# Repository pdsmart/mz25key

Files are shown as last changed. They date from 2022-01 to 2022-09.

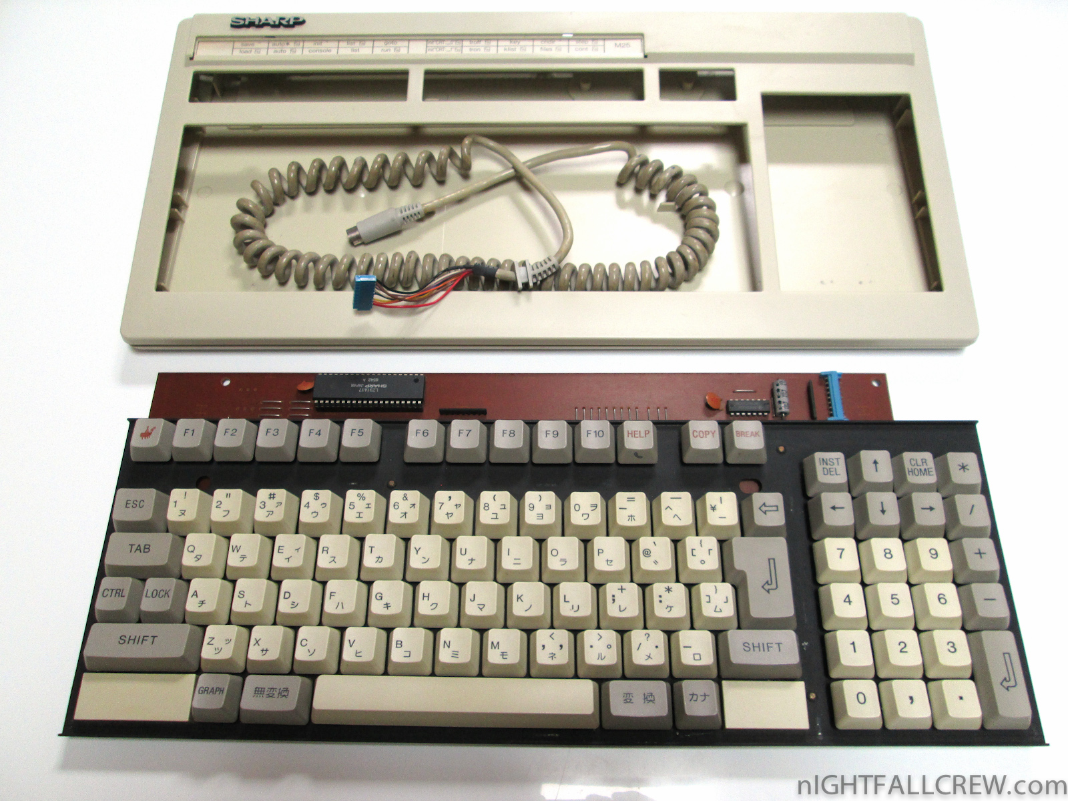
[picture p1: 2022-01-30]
docs/KeyboardImage.jpg

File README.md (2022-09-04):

# mz25key
A PS/2 to Sharp MZ-2500/MZ-2800 Interface

The mz25key now uses the SharKey firmware. If the build configuration (menuconfig -> SharpKey Configuration -> Build target -> mz25key
is set to an MZ2500 or MZ2800 then no changes are needed to hardware, just upload the firmware via the programmer port and once uploaded
future updates can be made via OTA. 

A modification can be made to an mz25key to allow it to run SharpKey firmware without specific build target. This can be achieved with a
100R resistor placed between pin14 (GPIO12) of the ESP32 and pin 8 of the host interface header J1. The advantage of this modification is it makes
the mz25key compatible with the SharpKey and if you used a 9pin header on the host interface, you can swap cables around to target different 
hosts.

Please see my website, https://eaw.app for more documentation and recent updates. 

The source code for the mz25key is identical to the SharpKey, just the build time configuration via the KConfig menu. The provided sdkconfig
is setup so that the source code will build the mz25key.

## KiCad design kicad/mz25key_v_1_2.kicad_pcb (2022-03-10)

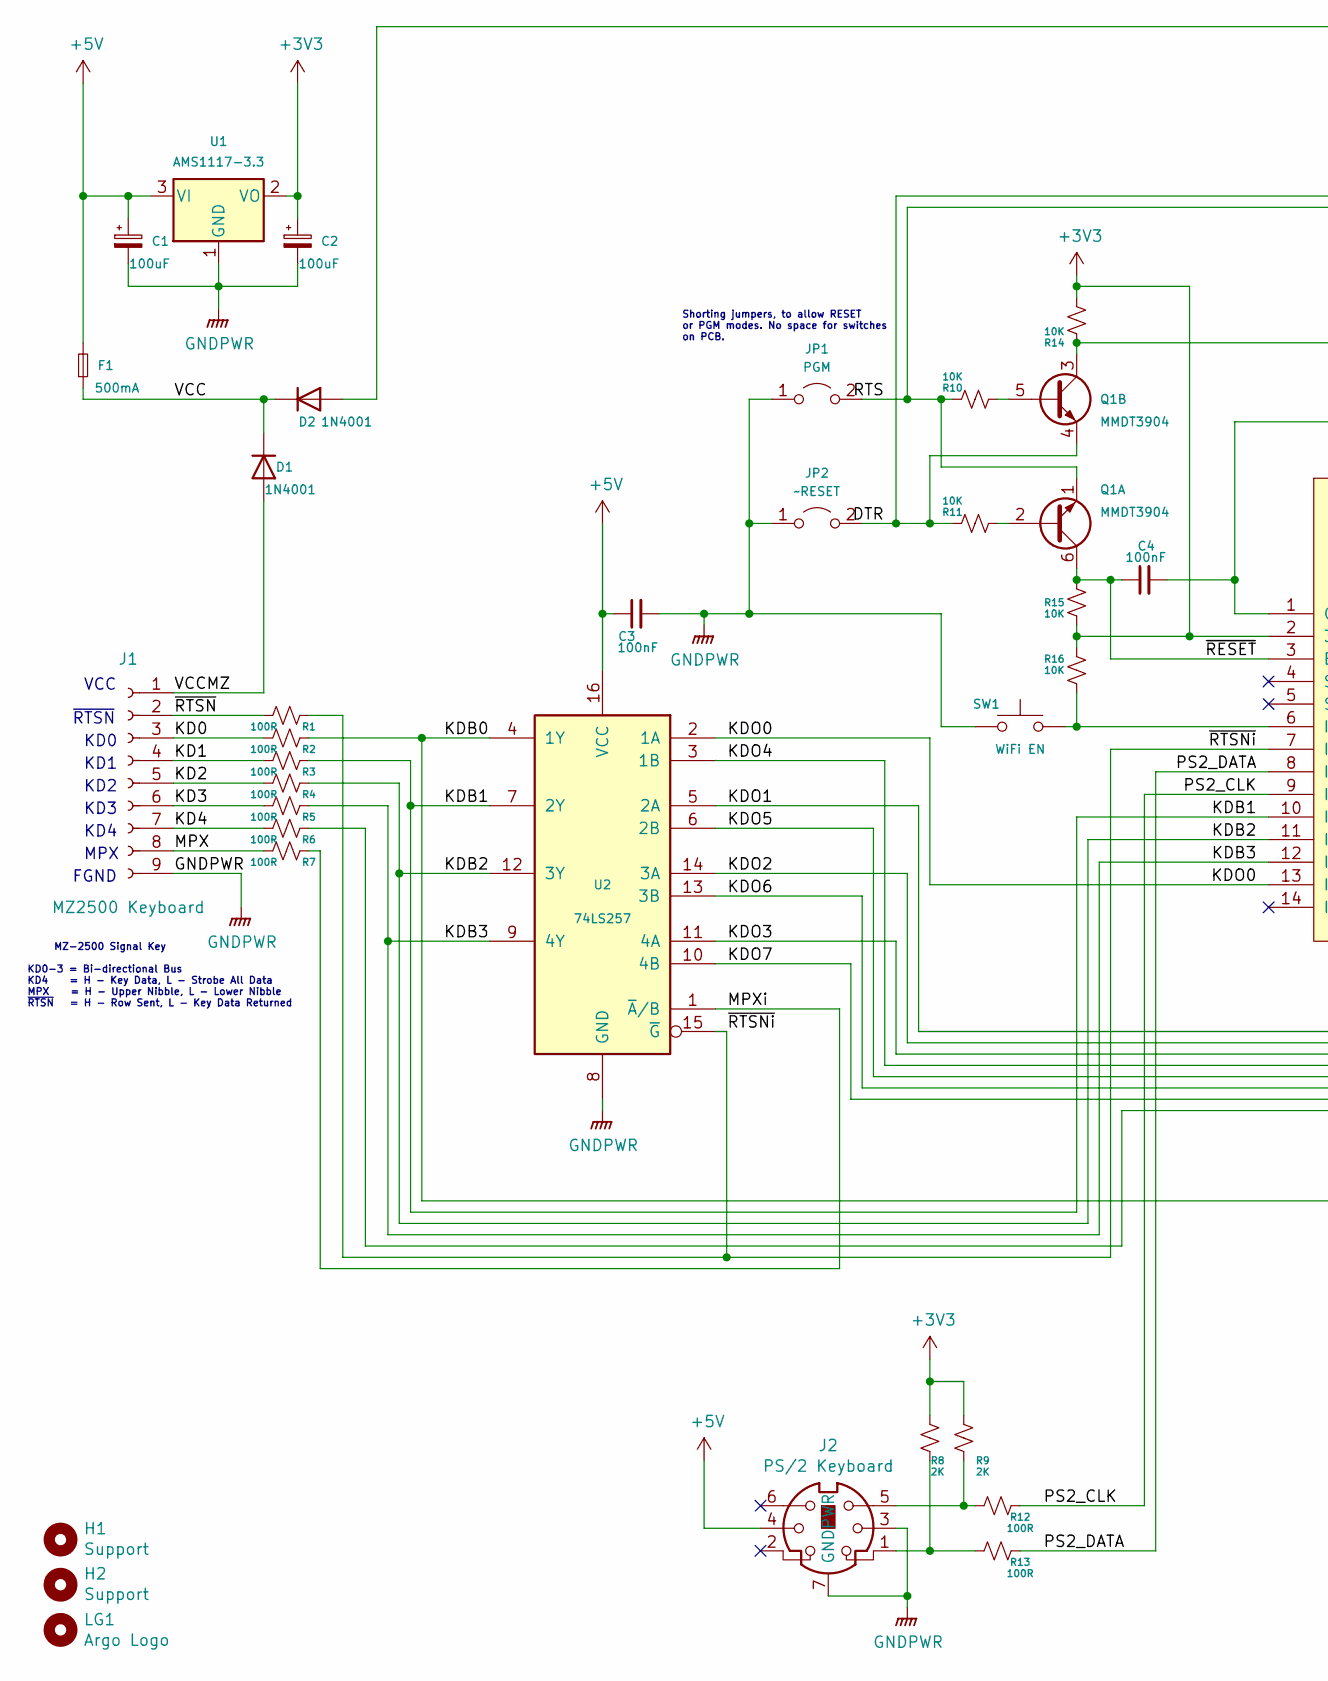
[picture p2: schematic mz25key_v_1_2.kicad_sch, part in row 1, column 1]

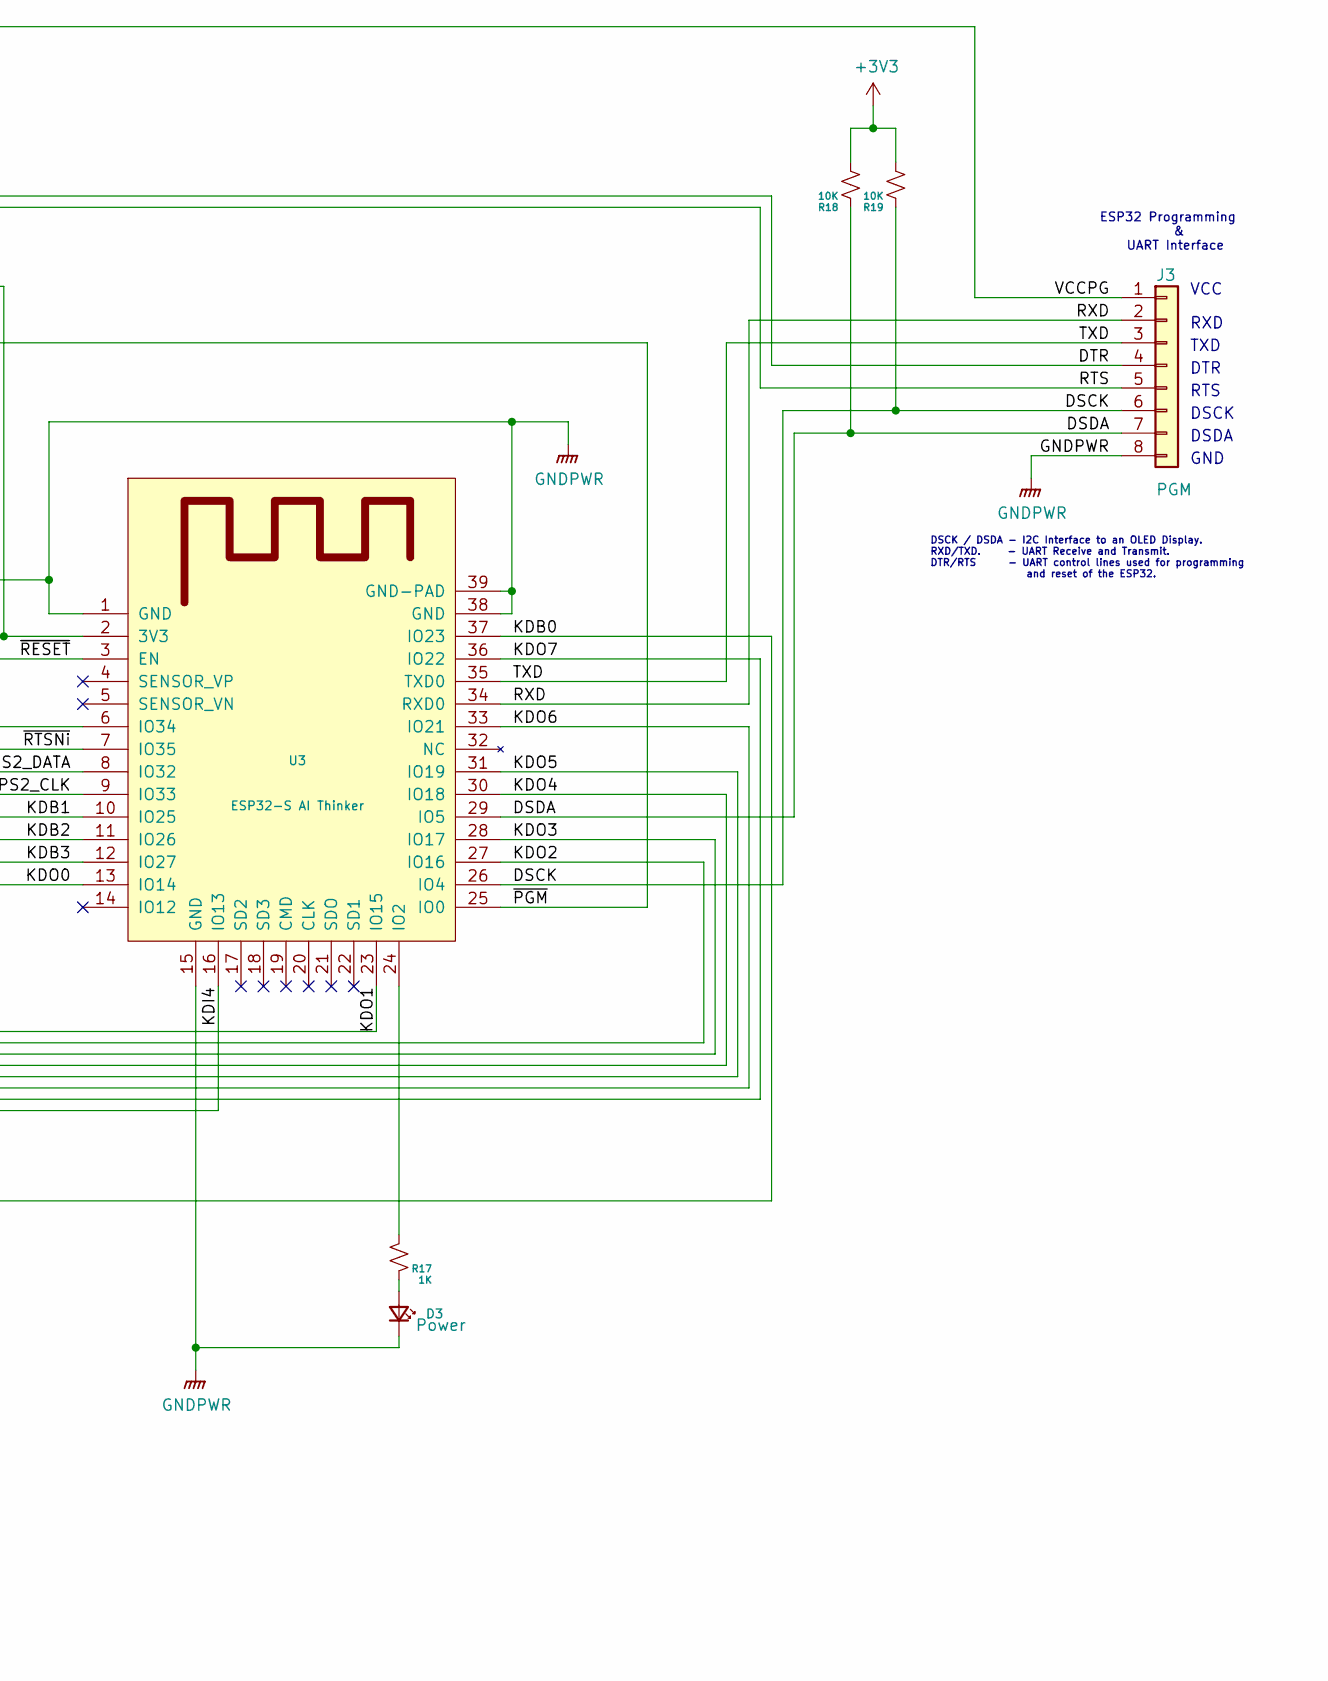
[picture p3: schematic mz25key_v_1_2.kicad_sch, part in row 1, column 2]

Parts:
C1, C2: 100uF; C_1210_3225Metric_Pad1.42x2.65mm_HandSolder
C3, C4: 100nF; C_0805_2012Metric
D1, D2: 1N4001; D_1206_3216Metric
D3: Power; LED_D3.0mm_Clear
F1: 500mA; Fuse_1806_4516Metric
H1, H2: Support; MountingHole_2.1mm
J1: MZ2500 Keyboard; PinHeader_1x09_P2.00mm_Vertical
J2: PS/2 Keyboard; Mini_din6_ps2
J3: PGM; PinHeader_1x08_P2.00mm_Vertical
JP1: PGM; PinHeader_1x02_P1.27mm_Vertical
JP2: ~RESET; PinHeader_1x02_P1.27mm_Vertical
LG1: Argo Logo; Argo
Q1: MMDT3904; SOT-363_SC-70-6
R1, R2, R3, R4, R5, R6, R7, R12, R13: 100R; R_0805_2012Metric
R8, R9: 2K; R_0805_2012Metric
R10, R11, R14, R15, R16, R18, R19: 10K; R_0805_2012Metric
R17: 1K; R_0805_2012Metric
SW1: WiFi EN; SW_SPST_B3S-1000
U1: AMS1117-3.3; SOT-223-3_TabPin2
U2: 74LS257; SOIC-16_3.9x9.9mm_P1.27mm
U3: ESP32-S AI Thinker; ESP32-S

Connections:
+3V3: C2.1, R8.1, R9.1, R14.2, R15.1, R16.2, R18.2, R19.2, U1.2 (VO), U3.2 (3V3)
+5V: C1.1, C3.1, F1.2, J2.4, U1.3 (VI), U2.16 (VCC)
/DSCK: J3.6, R19.1, U3.26 (IO4)
/DSDA: J3.7, R18.1, U3.29 (IO5)
/DTR: J3.4, JP2.2 (B), Q1.4 (E2), R11.2
/KD0: J1.3, R2.1
/KD1: J1.4, R3.1
/KD2: J1.5, R4.1
/KD3: J1.6, R5.1
/KD4: J1.7, R6.1
/KDB0: R2.2, U2.4 (1Y), U3.37 (IO23)
/KDB1: R3.2, U2.7 (2Y), U3.10 (IO25)
/KDB2: R4.2, U2.12 (3Y), U3.11 (IO26)
/KDB3: R5.2, U2.9 (4Y), U3.12 (IO27)
/KDI4: R6.2, U3.16 (IO13)
/KDO0: U2.2 (1A), U3.13 (IO14)
/KDO1: U2.5 (2A), U3.23 (IO15)
/KDO2: U2.14 (3A), U3.27 (IO16)
/KDO3: U2.11 (4A), U3.28 (IO17)
/KDO4: U2.3 (1B), U3.30 (IO18)
/KDO5: U2.6 (2B), U3.31 (IO19)
/KDO6: U2.13 (3B), U3.33 (IO21)
/KDO7: U2.10 (4B), U3.36 (IO22)
/MPX: J1.8, R7.1
/MPXi: R7.2, U2.1 (~A/B)
/PS2_CLK: R12.2, U3.9 (IO33)
/PS2_DATA: R13.2, U3.8 (IO32)
/RTS: J3.5, JP1.2 (B), Q1.1 (E1), R10.2
/RXD: J3.2, U3.34 (RXD0)
/TXD: J3.3, U3.35 (TXD0)
/VCC: D1.1 (K), D2.1 (K), F1.1
/VCCMZ: D1.2 (A), J1.1
/VCCPG: D2.2 (A), J3.1
/~PGM: Q1.3 (C2), R14.1, U3.25 (IO0)
/~RESET: C4.1, Q1.6 (C1), R15.2, U3.3 (EN)
/~RTSNi: R1.2, U2.15 (~G), U3.7 (IO35)
/~RTSN: J1.2, R1.1
GNDPWR: C1.2, C2.2, C3.2, C4.2, D3.1 (K), J1.9, J2.3, J2.7 (GNDPWR), J2.GND, J3.8, JP1.1 (A), JP2.1 (A), SW1.1, U1.1 (GND), U2.8 (GND), U3.1 (GND), U3.15 (GND), U3.38 (GND), U3.39 (GND-PAD)
unnamed: D3.2 (A), R17.2
unnamed: J2.1, R8.2, R13.1
unnamed: J2.5, R9.2, R12.1
unnamed: Q1.2 (B1), R11.1
unnamed: Q1.5 (B2), R10.1
unnamed: R16.1, SW1.2, U3.6 (IO34)
unnamed: R17.1, U3.24 (IO2)

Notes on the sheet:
KD3
Shorting jumpers, to allow RESET or PGM modes. No space for switches on PCB.
~{RTSN}
MPX
DSCK
DTR
RTS
KD2
TXD
VCC
ESP32 Programming & UART Interface
RXD
DSCK / DSDA - I2C Interface to an OLED Display. RXD/TXD. - UART Receive and Transmit. DTR/RTS - UART control lines used for programming and reset of the ESP32.
KD0
KD4
FGND
KD1
MZ-2500 Signal Key KD0-3 = Bi-directional Bus KD4 = H - Key Data, L - Strobe All Data MPX = H - Upper Nibble, L - Lower Nibble ~{RTSN} = H - Row Sent, L - Key Data Returned
DSDA
GND

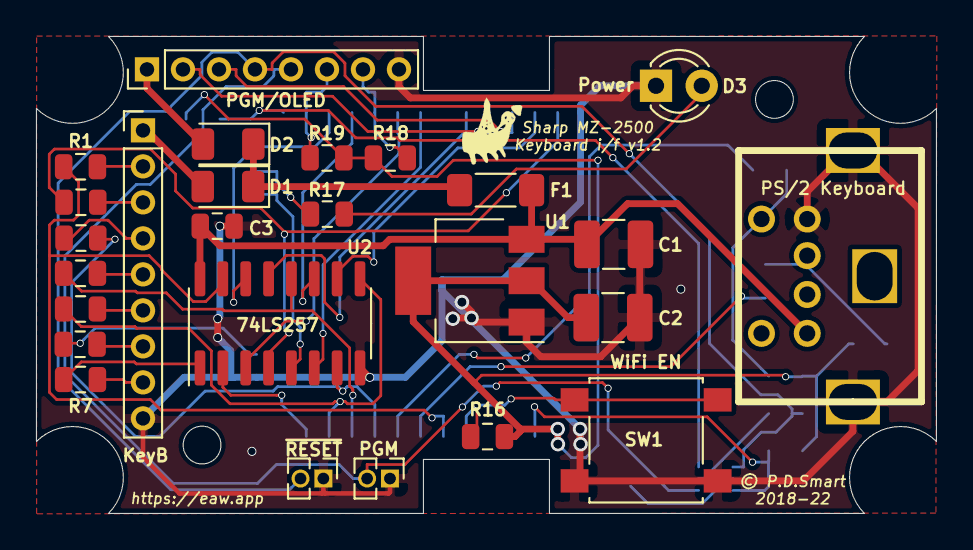
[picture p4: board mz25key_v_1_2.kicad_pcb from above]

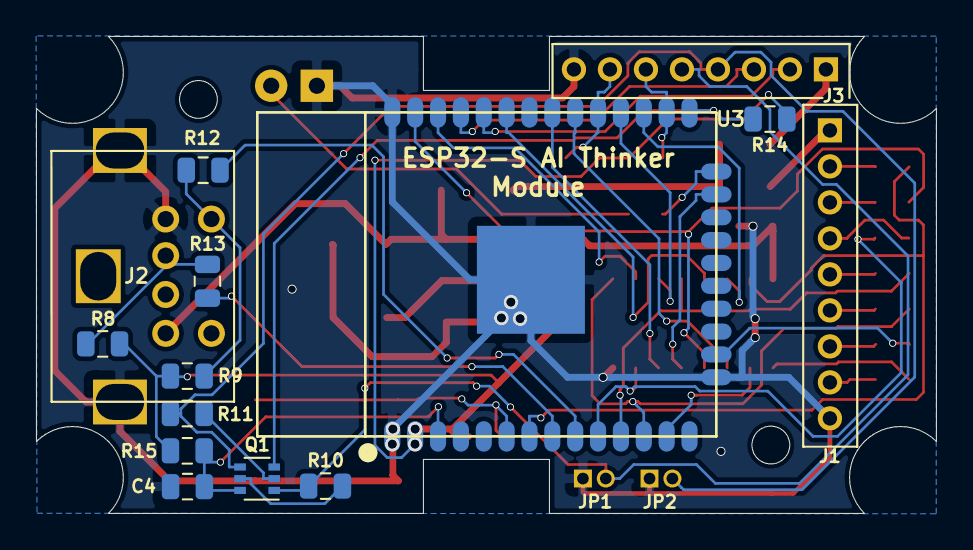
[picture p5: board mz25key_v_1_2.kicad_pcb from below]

Board: 2 copper layers, 50.0 x 26.5 mm, 40 parts (11 on the bottom side), 45 nets.

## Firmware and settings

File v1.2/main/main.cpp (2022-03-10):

/////////////////////////////////////////////////////////////////////////////////////////////////////////
//
// Name:            main.cpp
// Created:         Jan 2022
// Version:         v1.0
// Author(s):       Philip Smart
// Description:     MZ2500/2800 Key Matrix logic.
//                  This source file contains the application logic to obtain PS/2 scan codes, map them
//                  into a virtual keyboard matrix as per the Sharp MZ series key matrix and the
//                  logic to transmit the virtual key matrix to the MZ2500/2800.
//
//                  The application uses a modified version of the PS2KeyAdvanced 
//                  https://github.com/techpaul/PS2KeyAdvanced class from Paul Carpenter.
//
//                  The application uses, for debug purposes, the esp-idf-ssd1306 class from nopnop2002
//                  https://github.com/nopnop2002/esp-idf-ssd1306.
//
//                  The application uses the Espressif Development environment with Arduino components.
//                  This is necessary for the PS2KeyAdvanced class, which I may in future convert to
//                  use esp-idf library calls rather than Arduino.
//
//                  The Espressif environment is necessary in order to have more control over the build.
//                  It is important, for timing, that Core 1 is dedicated to MZ Interface 
//                  logic and Core 0 is used for all RTOS/Interrupts tasks. 
//
//                  The application is configured via the Kconfig system. Use 'idf.py menuconfig' to 
//                  configure.
// Credits:         
// Copyright:       (c) 2022 Philip Smart <philip.smart@net2net.org>
//
// History:         Jan 2022 - Initial write.
//                  Feb 2022 - Updates and fixes. Added logic to detect PS/2 disconnect and reconnect,
//                             added 3 alternative maps selected by ALT+F1 (MZ2500), ALT+F2(MZ2000)
//                             ALT+F3(MZ80B) due to slight differences in the key layout.
//                             Added framework for wifi so that the interface can enter AP mode to
//                             acquire local net parameters then connect to local net. Needs the web
//                             interface writing.
//
// Notes:           See Makefile to enable/disable conditional components
//
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
#include <stdio.h>
#include <stdlib.h>
#include <string.h>
#include "freertos/FreeRTOS.h"
#include "freertos/task.h"
#include "esp_log.h"
#if defined(CONFIG_MZ_WIFI_ENABLED)
  #include "freertos/event_groups.h"
  #include "esp_system.h"
  #include "esp_wifi.h"
  #include "esp_event.h"
  #include "nvs_flash.h"
  #include "lwip/err.h"
  #include "lwip/sys.h"
#endif
#include "Arduino.h"
#include "driver/gpio.h"
#include "soc/timer_group_struct.h"
#include "soc/timer_group_reg.h"
#include "PS2KeyAdvanced.h"
#include "MZKeyTable.h"
#include "ssd1306.h"
#include "font8x8_basic.h"
#include "sdkconfig.h"

//////////////////////////////////////////////////////////////////////////
// Important:
//
// All configuration is performed via the 'idf.py menuconfig' command.
// The file 'sdkconfig' contains the configured parameter defines.
//////////////////////////////////////////////////////////////////////////

// Macros.
//
#define NUMELEM(a)  (sizeof(a)/sizeof(a[0]))

// Structure to manage the translated key matrix. This is updated by the ps2Interface thread and read by the mzInterface thead.
typedef struct {
    uint8_t                     strobeAll;
    uint32_t                    strobeAllAsGPIO;
    uint8_t                     keyMatrix[16];
    uint32_t                    keyMatrixAsGPIO[16];
    uint8_t                     activeKeyMap;
} t_mzControl;
volatile t_mzControl            mzControl  = { 0xFF, 0x00000000, 
                                               { 0xFF, 0xFF, 0xFF, 0xFF, 0xFF, 0xFF, 0xFF, 0xFF, 0xFF, 0xFF, 0xFF, 0xFF, 0xFF, 0xFF, 0xFF, 0xFF}, 
                                               { 0x00000000, 0x00000000, 0x00000000, 0x00000000, 0x00000000, 0x00000000, 0x00000000, 0x00000000, 0x00000000, 0x00000000, 0x00000000, 0x00000000, 0x00000000, 0x00000000, 0x00000000  },
                                               MZ_ALL
                                             };

// Instantiate base classes. First, production required objects.
PS2KeyAdvanced                  Keyboard;

// Debug required objects.
SSD1306_t                       SSD1306;

// Handle to interact with the mz-2500/mz-2800 interface, ps/2 interface and wifi threads.
#if defined(CONFIG_MODEL_MZ2500)
    TaskHandle_t                TaskMZ25IF = NULL;
#endif
#if defined(CONFIG_MODEL_MZ2800)
    TaskHandle_t                TaskMZ28IF = NULL;
#endif
TaskHandle_t                    TaskPS2IF  = NULL;
#if defined(CONFIG_MZ_WIFI_ENABLED)
    TaskHandle_t                TaskWIFI   = NULL;
#endif

// Spin lock mutex to hold a core tied to an uninterruptable method. This only works on dual core ESP32's.
static portMUX_TYPE             mzMutex  = portMUX_INITIALIZER_UNLOCKED;

// Tag for ESP main application logging.
#if defined(CONFIG_MODEL_MZ2500)
  #define                       MAINTAG  "mz25key"
#endif
#if defined(CONFIG_MODEL_MZ2800)
  #define                       MAINTAG  "mz28key"
#endif

#if defined(CONFIG_MZ_WIFI_ENABLED)
    // The event group allows multiple bits for each event, but we only care about two events:
    // - we are connected to the AP with an IP
    // - we failed to connect after the maximum amount of retries 
    #define WIFI_CONNECTED_BIT  BIT0
    #define WIFI_FAIL_BIT       BIT1

    // Tag for ESP WiFi logging.
    #define                     WIFITAG  "wifi"

    // Menu selection types.
    enum WIFIMODES {
        WIFI_OFF              = 0x00,                             // WiFi is disabled.
        WIFI_ON               = 0x01,                             // WiFi is enabled.
        WIFI_CONFIG_AP        = 0x02                              // WiFi is set to enable Access Point to configure WiFi settings.
    };

    // Flag to indicate WiFi is active. Whilst active the MZ25 interface cannot run as it has to 
    // free the core. Need to find a way around this to make wifi only work on one core!
    static    bool              wifiActivated = 0;

    // FreeRTOS event group to signal when we are connected
    static EventGroupHandle_t   s_wifi_event_group;


    static int                  clientRetryCnt = 0;
#endif

#if defined(CONFIG_DEBUG_OLED) || !defined(CONFIG_OLED_DISABLED)
    // Printf to debug console terminal.
    void dbgprintf(const char * format, ...)
    {
        // Locals.
        va_list     ap;
    
        // Commence variable argument processing.
        va_start(ap, format);
        // Use vararg printf to expand and return the buffer size needed.
        int size = vsnprintf(nullptr, 0, format, ap) + 1;
        if (size > 0) 
        {
            va_end(ap);
    
            // Repeat and this time output the expanded string to a buffer for printing.
            va_start(ap, format);
            char buf[size + 1];
            vsnprintf(buf, size, format, ap);
    
            // Output to LED or console, currently via printf!
            printf(buf);
        }
        va_end(ap);
    }
#else
    #define dbgprintf(a, ...) {};
#endif

// Method to connect and interact with the MZ-2500 keyboard controller. This method is seperate from the MZ-2800
// as the scan is different and as it is time critical it is better to be per target machine.
//
// The basic requirement is to:
//   1. Detect a falling edge on the RTSN signal
//   2. Read the provided ROW number.
//   3. Lookup the matrix data for given ROW.
//   4. Output data to LS257 Mux.
//   5. Wait for RTSN to return inactive.
//   5. Loop
//
//   The ps2Interface method is responsible for obtaining a PS/2 Keyboard scancode and
//   creating the corresponding virtual matrix.
//
//   NB: As this method holds Core 1 under spinlock, no FreeRTOS or Arduino access 
//   can be made except for basic I/O ports. The spinlock has to be released for non
//   I/O work.
//
// The MZ timing period is ~600ns RTSN Low to High (Latch Row data coming from MZ machine),
// MPX (connected direct to external Quad 2-1 Mux goes high as RTSN goes low, the MPX
// signal is held high for 300ns then goes low for 300ns. The period when RTSN is low is
// when the MZ machine reads the scan row data. The cycle is ~1.2uS repeating, 14 rows
// so ~16.8uS for one full key matrix, The MZ machine if stuck in a tight loop will take
// approx 100uS to scan the matrix so the Gate Arrays are over sampling 6 times.
//
// WARNING: The GPIO's are configurable via menuconfig BUT it is assumed all except RTSNi
//          are in the first GPIO bank and RTSNi is in the second GPIO bank. Modify the code
//          if RTSNi is set in the first bank or KDB[3:0], KDI4 are in the second bank.
//
#if defined(CONFIG_MODEL_MZ2500)
    IRAM_ATTR void mz25Interface( void * pvParameters )
    {
        // Locals.
        volatile uint32_t gpioIN;
        volatile uint8_t  strobeRow = 1;
    
        // Mask values declared as variables, let the optimiser decide wether they are constants or placed in-memory.
        uint32_t          rowBitMask = (1 << CONFIG_MZ_KDB3) | (1 << CONFIG_MZ_KDB2) | (1 << CONFIG_MZ_KDB1) | (1 << CONFIG_MZ_KDB0);
        uint32_t          colBitMask = (1 << CONFIG_MZ_KDO7) | (1 << CONFIG_MZ_KDO6) | (1 << CONFIG_MZ_KDO5) | (1 << CONFIG_MZ_KDO4) | 
                                       (1 << CONFIG_MZ_KDO3) | (1 << CONFIG_MZ_KDO2) | (1 << CONFIG_MZ_KDO1) | (1 << CONFIG_MZ_KDO0);
        uint32_t          KDB3_MASK  = (1 << CONFIG_MZ_KDB3);
        uint32_t          KDB2_MASK  = (1 << CONFIG_MZ_KDB2);
        uint32_t          KDB1_MASK  = (1 << CONFIG_MZ_KDB1);
        uint32_t          KDB0_MASK  = (1 << CONFIG_MZ_KDB0);
        uint32_t          KDI4_MASK  = (1 << CONFIG_MZ_KDI4);
        uint32_t          RTSNI_MASK = (1 << (CONFIG_MZ_RTSNI - 32));
    
        ESP_LOGI(MAINTAG, "Starting mz25Interface thread, colBitMask=%08x, rowBitMask=%08x.", colBitMask, rowBitMask);
    
        // Create, initialise and hold a spinlock so the current core is bound to this one method.
        portENTER_CRITICAL(&mzMutex);
    
        // Permanent loop, just wait for an RTSN strobe, latch the row, lookup matrix and output.
        // Timings with Power LED = LED Off to On = 108ns, LED On to Off = 392ns
        for(;;)
        {
            #if defined(CONFIG_MZ_WIFI_ENABLED)
                // Whilst Wifi is active, suspend processing as we need to free up the core.
                if(wifiActivated)
                {
                    portEXIT_CRITICAL(&mzMutex);
                    while(wifiActivated);
                portENTER_CRITICAL(&mzMutex);
                }
            #endif
    
            // Detect RTSN going high, the MZ will send the required row during this cycle.
            if(REG_READ(GPIO_IN1_REG) & RTSNI_MASK)
            {
                // Read the GPIO ports to get latest Row and KDI4 states.
                gpioIN = REG_READ(GPIO_IN_REG);
    
                // Assemble the required matrix row from the configured bits.
                strobeRow = ((gpioIN&KDB3_MASK) >> (CONFIG_MZ_KDB3-3)) | ((gpioIN&KDB2_MASK) >> (CONFIG_MZ_KDB2-2)) | ((gpioIN&KDB1_MASK) >> (CONFIG_MZ_KDB1-1)) | ((gpioIN&KDB0_MASK) >> CONFIG_MZ_KDB0);
             
                // Clear all KDO bits - clear state = '1'
                GPIO.out_w1ts = colBitMask;                                // Reset all scan data bits to '1', inactive.
    
                // KDI4 indicates if row data is needed or a single byte ANDing all the keys together, ie. to detect a key press without strobing all rows.
                if(gpioIN & KDI4_MASK)
                {
                    // Set all required KDO bits according to keyMatrix, set state = '0'.
                    GPIO.out_w1tc = mzControl.keyMatrixAsGPIO[strobeRow];  // Set to '0' active bits.
                } else
                {
                    // Set all required KDO bits according to the strobe all value. set state = '0'.
                    GPIO.out_w1tc = mzControl.strobeAllAsGPIO;             // Set to '0' active bits.
                }
    
                // Wait for RTSN to go low. No lockup guarding as timing is critical also the watchdog is disabled, if RTSN never goes low then the user has probably unplugged the interface!
                while(REG_READ(GPIO_IN1_REG) & RTSNI_MASK);
            }
    
            // Logic to feed the watchdog if needed. Watchdog disabled in menuconfig but if enabled this will need to be used.
            //TIMERG0.wdt_wprotect=TIMG_WDT_WKEY_VALUE; // write enable
            //TIMERG0.wdt_feed=1;                       // feed dog
            //TIMERG0.wdt_wprotect=0;                   // write protect
            //TIMERG1.wdt_wprotect=TIMG_WDT_WKEY_VALUE; // write enable
            //TIMERG1.wdt_feed=1;                       // feed dog
            //TIMERG1.wdt_wprotect=0;                   // write protect
        }
    }
#endif

// Method to connect and interact with the MZ-2800 keyboard controller. This method is seperate from the MZ-2500
// as the scan is different and as it is time critical it needs to be per target machine.
//
// The basic requirement is to:
//   1. Detect a rising edge on the RTSN signal
//   2. Wait at least 200ns before sampling KD4
//   3. Wait at least 650ns before reading ROW.
//   4. Read the provided ROW number.
//   5. If KD4 = 0 then output logical AND of all columns to LS257 Mux.
//   6. If KD4 = 1 then lookup data for given row and output to LS257 Mux.
//   7. Wait for RTSN to return low.
//   7. Loop
//
//   The ps2Interface method is responsible for obtaining a PS/2 Keyboard scancode and
//   creating the corresponding virtual matrix.
//
//   NB: As this method holds Core 1 under spinlock, no FreeRTOS or Arduino access 
//   can be made except for basic I/O ports. The spinlock has to be released for non
//   I/O work.
//
// The MZ 2800 timing period is 1.78uS RTSN going active high, KD4 changing state 150ns after RTSN goes active,
// ROW number being set 650ns after RTSN goes active. MPX directly controls the LS257 latch so only need to write out
// and 8 bit value prior to RTSN going inactive.
// Normally the keyboard is in STROBE ALL mode. When a key is pressed, it commences a scan and when it arrives at the pressed
// key, RTSN cycle is suspended for varying amounts of time (ie 500us or 19ms) as the controller is looking for debounce and repeat.
//
// WARNING: The GPIO's are configurable via menuconfig BUT it is assumed all except RTSNi
//          are in the first GPIO bank and RTSNi is in the second GPIO bank. Modify the code
//          if RTSNi is set in the first bank or KDB[3:0], KDI4 are in the second bank.
//
#if defined(CONFIG_MODEL_MZ2800)
    IRAM_ATTR void mz28Interface( void * pvParameters )
    {
        // Locals.
        volatile uint32_t gpioIN;
        volatile uint8_t  strobeRow = 1;
    
        // Mask values declared as variables, let the optimiser decide wether they are constants or placed in-memory.
        uint32_t          rowBitMask = (1 << CONFIG_MZ_KDB3) | (1 << CONFIG_MZ_KDB2) | (1 << CONFIG_MZ_KDB1) | (1 << CONFIG_MZ_KDB0);
        uint32_t          colBitMask = (1 << CONFIG_MZ_KDO7) | (1 << CONFIG_MZ_KDO6) | (1 << CONFIG_MZ_KDO5) | (1 << CONFIG_MZ_KDO4) | 
                                       (1 << CONFIG_MZ_KDO3) | (1 << CONFIG_MZ_KDO2) | (1 << CONFIG_MZ_KDO1) | (1 << CONFIG_MZ_KDO0);
        uint32_t          KDB3_MASK  = (1 << CONFIG_MZ_KDB3);
        uint32_t          KDB2_MASK  = (1 << CONFIG_MZ_KDB2);
        uint32_t          KDB1_MASK  = (1 << CONFIG_MZ_KDB1);
        uint32_t          KDB0_MASK  = (1 << CONFIG_MZ_KDB0);
        uint32_t          KDI4_MASK  = (1 << CONFIG_MZ_KDI4);
        uint32_t          RTSNI_MASK = (1 << (CONFIG_MZ_RTSNI - 32));
    
        ESP_LOGI(MAINTAG, "Starting mz28Interface thread, colBitMask=%08x, rowBitMask=%08x.", colBitMask, rowBitMask);
    
        // Create, initialise and hold a spinlock so the current core is bound to this one method.
        portENTER_CRITICAL(&mzMutex);
    
        // Permanent loop, just wait for an RTSN strobe, latch the row, lookup matrix and output.
        for(;;)
        {
            #if defined(CONFIG_MZ_WIFI_ENABLED)
                // Whilst Wifi is active, suspend processing as we need to free up the core.
                if(wifiActivated)
                {
                    portEXIT_CRITICAL(&mzMutex);
                    while(wifiActivated);
                portENTER_CRITICAL(&mzMutex);
                }
            #endif
              
            // Detect RTSN going high, the MZ will send the required row during this cycle.
            if(REG_READ(GPIO_IN1_REG) & RTSNI_MASK)
            {
                // Slight delay needed as KD4 lags behind RTSN by approx 200ns and ROW number lags 850ns behind RTSN.
                for(volatile uint32_t delay=0; delay < 8; delay++);

                // Read the GPIO ports to get latest Row and KDI4 states.
                gpioIN = REG_READ(GPIO_IN_REG);
    
                // Assemble the required matrix row from the configured bits.
                strobeRow = ((gpioIN&KDB3_MASK) >> (CONFIG_MZ_KDB3-3)) | ((gpioIN&KDB2_MASK) >> (CONFIG_MZ_KDB2-2)) | ((gpioIN&KDB1_MASK) >> (CONFIG_MZ_KDB1-1)) | ((gpioIN&KDB0_MASK) >> CONFIG_MZ_KDB0);
             
                // Clear all KDO bits - clear state = '1'
                GPIO.out_w1ts = colBitMask;                                // Reset all scan data bits to '1', inactive.

                // Another short delay once the row has been assembled as we dont want to change the latch setting too soon, changing too soon leads to ghosting on previous row.
                for(volatile uint32_t delay=0; delay < 5; delay++);
    
                // KDI4 indicates if row data is needed or a single byte ANDing all the keys together, ie. to detect a key press without strobing all rows.
                if(gpioIN & KDI4_MASK)
                {
                    // Set all required KDO bits according to keyMatrix, set state = '0'.
                    GPIO.out_w1tc = mzControl.keyMatrixAsGPIO[strobeRow];  // Set to '0' active bits.
                } else
                {
                    // Set all required KDO bits according to the strobe all value. set state = '0'.
                    GPIO.out_w1tc = mzControl.strobeAllAsGPIO;             // Set to '0' active bits.
                }
    
                // Wait for RTSN to go low. No lockup guarding as timing is critical also the watchdog is disabled, if RTSN never goes low then the user has probably unplugged the interface!
                while(REG_READ(GPIO_IN1_REG) & RTSNI_MASK);
            }
    
            // Logic to feed the watchdog if needed. Watchdog disabled in menuconfig but if enabled this will need to be used.
            //TIMERG0.wdt_wprotect=TIMG_WDT_WKEY_VALUE; // write enable
            //TIMERG0.wdt_feed=1;                       // feed dog
            //TIMERG0.wdt_wprotect=0;                   // write protect
            //TIMERG1.wdt_wprotect=TIMG_WDT_WKEY_VALUE; // write enable
            //TIMERG1.wdt_feed=1;                       // feed dog
            //TIMERG1.wdt_wprotect=0;                   // write protect
        }
    }
#endif
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
extern "C" void app_main()
{
    // Setup hardware and start primary control threads,
    setup();

    // Lost in space.... this thread is no longer required!
}

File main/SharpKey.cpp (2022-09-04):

/////////////////////////////////////////////////////////////////////////////////////////////////////////
//
// Name:            SharpKey.cpp
// Created:         Jan 2022
// Version:         v1.0
// Author(s):       Philip Smart
// Description:     HID (PS/2, Bluetooth) to Sharp Keyboard and Mouse Interface.
//                  This source file contains the application logic to interface several Sharp MZ/X
//                  machines to a HID (PS/2 keyboard, PS/2 Mouse, Bluetooth Keyboard/Mouse). The type
//                  of host is determined by the host i/o lines  and the necessary control threads 
//                  instantiated accordingly.
//
//                  Please see the individual classes (singleton obiects) for a specific host logic.
//
//                  The application uses the Espressif Development environment with Arduino components.
//                  This is necessary for the PS2KeyAdvanced class, which may in future be converted to
//                  use esp-idf library calls rather than Arduino. I wrote the PS2Mouse class using
//                  Arduino as well, so both will need conversion eventually.
//
//                  The Espressif environment is necessary in order to have more control over the build.
//                  It is important, for timing, that Core 1 is dedicated to the MZ 2599/2800 Interface 
//                  logic due to timing constraints and Core 0 is used for all RTOS/Interrupts tasks. 
//                  Other host interface classes freely use both cores.
//
//                  The application is configured via the Kconfig system. Use 'idf.py menuconfig' to 
//                  configure.
// Credits:         
// Copyright:       (c) 2022 Philip Smart <philip.smart@net2net.org>
//
// History:         Jan 2022 - Initial write.
//                  Feb 2022 - Updates and fixes. Added logic to detect PS/2 disconnect and reconnect,
//                             added 3 alternative maps selected by ALT+F1 (MZ2500), ALT+F2(MZ2000)
//                             ALT+F3(MZ80B) due to slight differences in the key layout.
//                             Added framework for wifi so that the interface can enter AP mode to
//                             acquire local net parameters then connect to local net. Needs the web
//                             interface writing.
//                  Mar 2022 - Split from mz25key and modularised to allow multiple host targets.
//                  Apr 2022 - Rewrote the application as C++ classes, the host interfaces are based
//                             on a Base class (KeyInterface) which virtualises the interface and
//                             provides some base methods and variables, each host inherits the Base class
//                             to form individual singleton objects.
//                  Apr 2022 - Added X1, X68000 Keyboard functionality and Mouse functionality.
//                  Apr 2022 - Started on tests for using Bluetooth, moved all input devices (Human
//                             Input Device) into its own class to encapsulate PS/2 Keyboard, Mouse and
//                             Bluetooth Keyboard/Mouse.
//            v1.01 May 2022 - More objectifying the fundamental components to make it easier to upgrade.
//            v1.02 May 2022 - Initial release version.
//            v1.03 May 2022 - Added feature security and efuse build data.
//            v1.04 Jun 2022 - Reworked the Wifi so that when requested, the SharpKey reboots and 
//                             immediately starts up in WiFi mode without enabling BT or hardware I/F.
//                             This is necessary due to shared antenna in the ESP32 and also clashes
//                             in the IDF library stack.
//
// Notes:           See Makefile to enable/disable conditional components
//
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
#include <stdio.h>
#include <stdlib.h>
#include <string.h>
#include <fstream>
#include <sstream>
#include <iostream>
#include <vector>
#include <iterator>
#include "freertos/FreeRTOS.h"
#include "freertos/task.h"
#include "esp_log.h"
#include "esp_system.h"
#include "esp_efuse.h"
#include "esp_efuse_table.h"
#include "esp_efuse_custom_table.h"
#include "nvs_flash.h"
#include "nvs.h"
#include "Arduino.h"
#include "driver/gpio.h"
#include "soc/timer_group_struct.h"
#include "soc/timer_group_reg.h"
#include "soc/soc.h"
#include "soc/rtc_cntl_reg.h"
#include "sdkconfig.h"
#include "MZ2528.h"
#include "X1.h"
#include "X68K.h"
#include "MZ5665.h"
#include "PC9801.h"
#include "Mouse.h"
#include "HID.h"
#include "NVS.h"
#include "WiFi.h"

//////////////////////////////////////////////////////////////////////////
// Important:
//
// All configuration is performed via the 'idf.py menuconfig' command.
// The file 'sdkconfig' contains the configured parameter defines.
//////////////////////////////////////////////////////////////////////////

// Constants.
#define SHARPKEY_NAME                  "SharpKey"
#define SHARPKEY_VERSION               1.04
#define SHARPKEY_MODULES               "SharpKey MZ2528 X1 X68K MZ5665 PC9801 Mouse KeyInterface HID NVS LED SWITCH WiFi FilePack"

// Tag for ESP main application logging.
#define MAINTAG                        "sharpkey"

// LittleFS default parameters.
#define LITTLEFS_DEFAULT_PATH          "/littlefs"
#define LITTLEFS_DEFAULT_PARTITION     "filesys"

// Structure for configuration information stored in NVS.
struct SharpKeyConfig {
    struct {
        uint8_t                 bootMode;               // Flag to indicate the mode SharpKey should boot into.
                                                        // 0 = Interface, 1 = WiFi (configured), 2 = WiFi (default).
    } params;
} sharpKeyConfig;

// Overloads for the EFUSE Custom MAC definitions. Limited Efuse space and Custom MAC not needed in eFuse in this design
// so we overload with custom flags.
// 0-7 Reserved
// 8-15 defined as Base configuration and enhanced set 1.
static const esp_efuse_desc_t ENABLE_BT[] = {
    {EFUSE_BLK3, 8, 1},
};
static const esp_efuse_desc_t ENABLE_MZ5665[] = {
    {EFUSE_BLK3, 9, 1},
};
static const esp_efuse_desc_t ENABLE_PC9801[] = {
    {EFUSE_BLK3, 10, 1},
};
static const esp_efuse_desc_t ENABLE_MOUSE[] = {
    {EFUSE_BLK3, 11, 1},
};
static const esp_efuse_desc_t ENABLE_X68000[] = {
    {EFUSE_BLK3, 12, 1},
};
static const esp_efuse_desc_t ENABLE_X1[] = {
    {EFUSE_BLK3, 13, 1},
};
static const esp_efuse_desc_t ENABLE_MZ2800[] = {
    {EFUSE_BLK3, 14, 1},
};
static const esp_efuse_desc_t ENABLE_MZ2500[] = {
    {EFUSE_BLK3, 15, 1},
};
const esp_efuse_desc_t* ESP_EFUSE_ENABLE_BT[] = {
    &ENABLE_BT[0],
    NULL
};
const esp_efuse_desc_t* ESP_EFUSE_ENABLE_MZ5665[] = {
    &ENABLE_MZ5665[0],
    NULL
};
const esp_efuse_desc_t* ESP_EFUSE_ENABLE_PC9801[] = {
    &ENABLE_PC9801[0],
    NULL
};
const esp_efuse_desc_t* ESP_EFUSE_ENABLE_X68000[] = {
    &ENABLE_X68000[0],
    NULL
};
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

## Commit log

2022-01-29 Updates with the mzInterface stage
2022-03-10 Added PCB and Schematic files
    [mz25key-B_Cu.gbr, mz25key-B_Mask.gbr, mz25key-B_Paste.gbr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]
2022-06-02 Updated to SharpKey firmware
    [sharpkey_partition_table.csv]

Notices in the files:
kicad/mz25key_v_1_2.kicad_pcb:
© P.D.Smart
